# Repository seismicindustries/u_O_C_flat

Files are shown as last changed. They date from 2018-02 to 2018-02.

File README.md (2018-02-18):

# u_O_C_flat
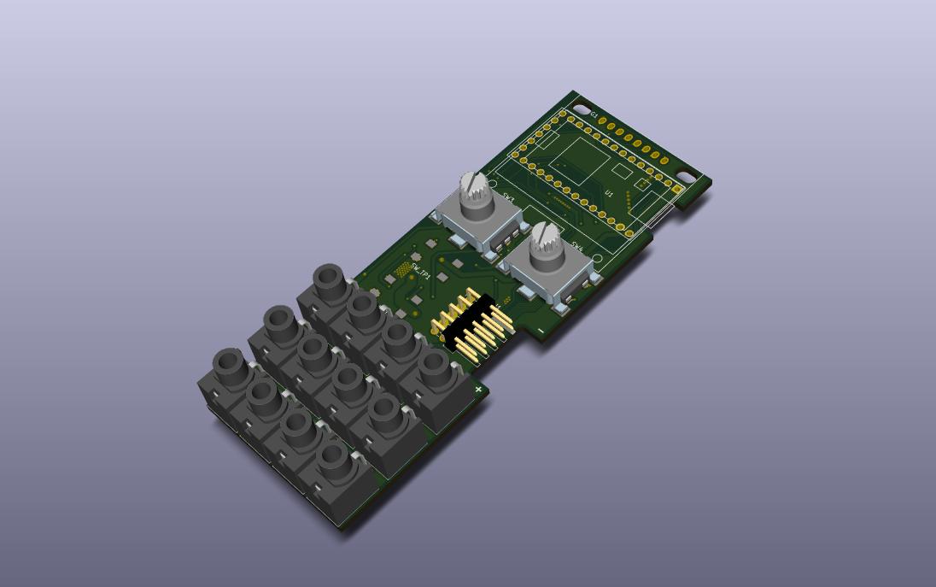
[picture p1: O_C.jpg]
render from kicad

same as the original

with the same formfactor as the u_O_C but different placement of the encoders and buttons

also the linear regulator has been replaced by a MP1469 regulator.

-> so far the design is untested. i made some PCB but i don't have my display yet...

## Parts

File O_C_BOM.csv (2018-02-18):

Refs | Value | Footprint | MFR | MPN | SPR | QTY | SPN
SW_BOT1;SW_TP1 | SW_PUSH_SMALL_H | raffilibkicad:APEM_tactile_SMD_switch_6mm | APEM | ADTSM66NV | Mouser | 2 | 642-ADTSM66NV
C1;C2;C4 | 22u | raffilibkicad:CP_Elec_7.3x4.3 | Panasonic | EEF-CX1D220R | Mouser | 3 | 667-EEF-CX1D220R
C5;C7;C8;C12;C11;C15;C26;C28;C27;C29 | 100n | raffilibkicad:C_0603 | Wurth Electronics | 8.85012E+11 | Mouser | 10 | 710-885012206095
C6 | 10u | raffilibkicad:C_0603 | TDK | C1608X5R0J106M080AB | Mouser | 1 | 810-C1608X5R0J106M
C3;C10;C14 | 1u | raffilibkicad:C_0603 | Murata | GCJ188R71E105KA01D | Mouser | 3 | 81-GCJ188R71E105KA1D
C22;C23;C24;C25 | 22p | raffilibkicad:C_0603 | Kemet | C0603C220J5GACTU | Mouser | 4 | 80-C0603C220J5G
C9;C16;C17;C18;C19;C20;C21;C13 | 470n | raffilibkicad:C_0603 | Taiyo Yuden | EMK107B7474KA-T | Mouser | 8 | 963-EMK107B7474KA-T
SW3;SW4 | Rotary_Encoder_Switch | raffilibkicad:ENCODER_PEC11_SMD | Bourns | PEC11S-9215K-H0015 | Mouser | 2 | 652-PEC11S9215KH0015
L1;L2 | 100n | raffilibkicad:Inductor_PSU_NLCV32T | TDK | NLCV32T-R10M-PFR | Mouser | 2 | 810-NLCV32T-R10M-PFR
L3 | 6u8 | raffilibkicad:Inductor_SRN4018TA_bourns | Bourns | SRN4018TA-6R8M | Mouser | 1 | 652-SRN4018TA-6R8M
G1 | Display128x64OLED | raffilibkicad:OLED_DISPLAY_128_64_1_3_inch |  |  |  | 1
J1 | CONN_02X05 | raffilibkicad:Pin_Header_Angled_2x05_Pitch2.54mm_with_space_for_con | Amphenol FCI | 649-68020-110HLF | Mouser | 1 | 68020-110HLF
R25;R26;R27;R28 | 100 | raffilibkicad:R_0603 |  |  | Mouser | 4 | 603-RC0603FR-07100RL
R1;R23;R24;R35;R36;R12;R14;R16;R18;R37;R38;R39;R40 | 100k | raffilibkicad:R_0603 | Vishay / Draloric | RCA0603100KJNEC | Mouser | 13 | 71-RCA0603100KJNEC
R43;R44;R45;R46 | 220 | raffilibkicad:R_0603 | Vishay | CRCW0603220RFKEB | Mouser | 4 | 71-CRCW0603220RFKEB
R31;R32;R33;R34 | 24k9 | raffilibkicad:R_0603 | Yageo | RC0603FR-0724K9L | Mouser | 4 | 603-RC0603FR-0724K9L
R6 | 2k | raffilibkicad:R_0603 | Yageo | RC0603FR-0724K9L | Mouser | 1 | 603-RC0603FR-072KL
R29;R30;R41;R42;R19;R20;R21;R22 | 33k | raffilibkicad:R_0603 | Panasonic | ERJ-3GEYJ333V | Mouser | 8 | 667-ERJ-3GEYJ333V
R3 | 40k2 | raffilibkicad:R_0603 |  |  | Mouser | 1 | 603-RC0805FR-0740K2L
R9;R10 | 47k | raffilibkicad:R_0603 | Yageo | RC0603FR-0747KL | Mouser | 2 | 603-RC0603FR-0747KL
R8;R7 | 510 | raffilibkicad:R_0603 | Yageo | RC0603FR-07510RL | Mouser | 2 | 603-RC0603FR-07510RL
R2;R5;R11;R13;R15;R17 | 75k | raffilibkicad:R_0603 | Bourns | CR0603-FX-2202ELF | Mouser | 6 | 652-CR0603FX-2202ELF
R4 | 7k68 | raffilibkicad:R_0603 |  |  | Mouser | 1 | 603-RC0805FR-077K68L
U4 | AP2210N-3.3TRG1_/_SOT23-3 | raffilibkicad:SOT-23 | Diodes Incorporated | AP2210N-3.3TRG1 | Mouser | 1 | 621-AP2210N-3.3TRG1
D1 | LM4040 5.0V | raffilibkicad:SOT-23 | Texas Instruments | LM4040C50IDBZR | Mouser | 1 | 595-LM4040C50IDBZR
Q1;Q2;Q3;Q4 | MMBT3904 | raffilibkicad:SOT-23 | Nexperia | MMBT3904,215 | Mouser | 4 | 771-MMBT3904T/R
U3 | MP1469 | raffilibkicad:SOT-23-6 | MPS | MP1469GJ-Z | Mouser | 1 | 946-MP1469GJZ
U5 | MCP6004 | raffilibkicad:TSSOP-14_4.4x5mm_Pitch0.65mm | Microchip | MCP6004T-I/ST | Mouser | 1 | 579-MCP6004T-I/ST
U6 | TL074 | raffilibkicad:TSSOP-14_4.4x5mm_Pitch0.65mm | Texas Instruments | TL074CPWR | Mouser | 1 | 595-TL074CPWR
U2 | DAC8565 | raffilibkicad:TSSOP-16_4.4x5mm_Pitch0.65mm | Texas Instruments | DAC8565ICPW | Mouser | 1 | 595-DAC8565ICPW
U1 | Teensy3.2 | raffilibkicad:Teensy_3_2 | SparkFun | DEV-13736 | Mouser | 1 | 474-DEV-13736
TR4;TR3;TR2;TR1;CVD1;CVC1;CVB1;CVA1;CV4;CV3;CV2;CV1 | JACK_QINGPU | raffilibkicad:jack_qingpu |  |  |  | 12

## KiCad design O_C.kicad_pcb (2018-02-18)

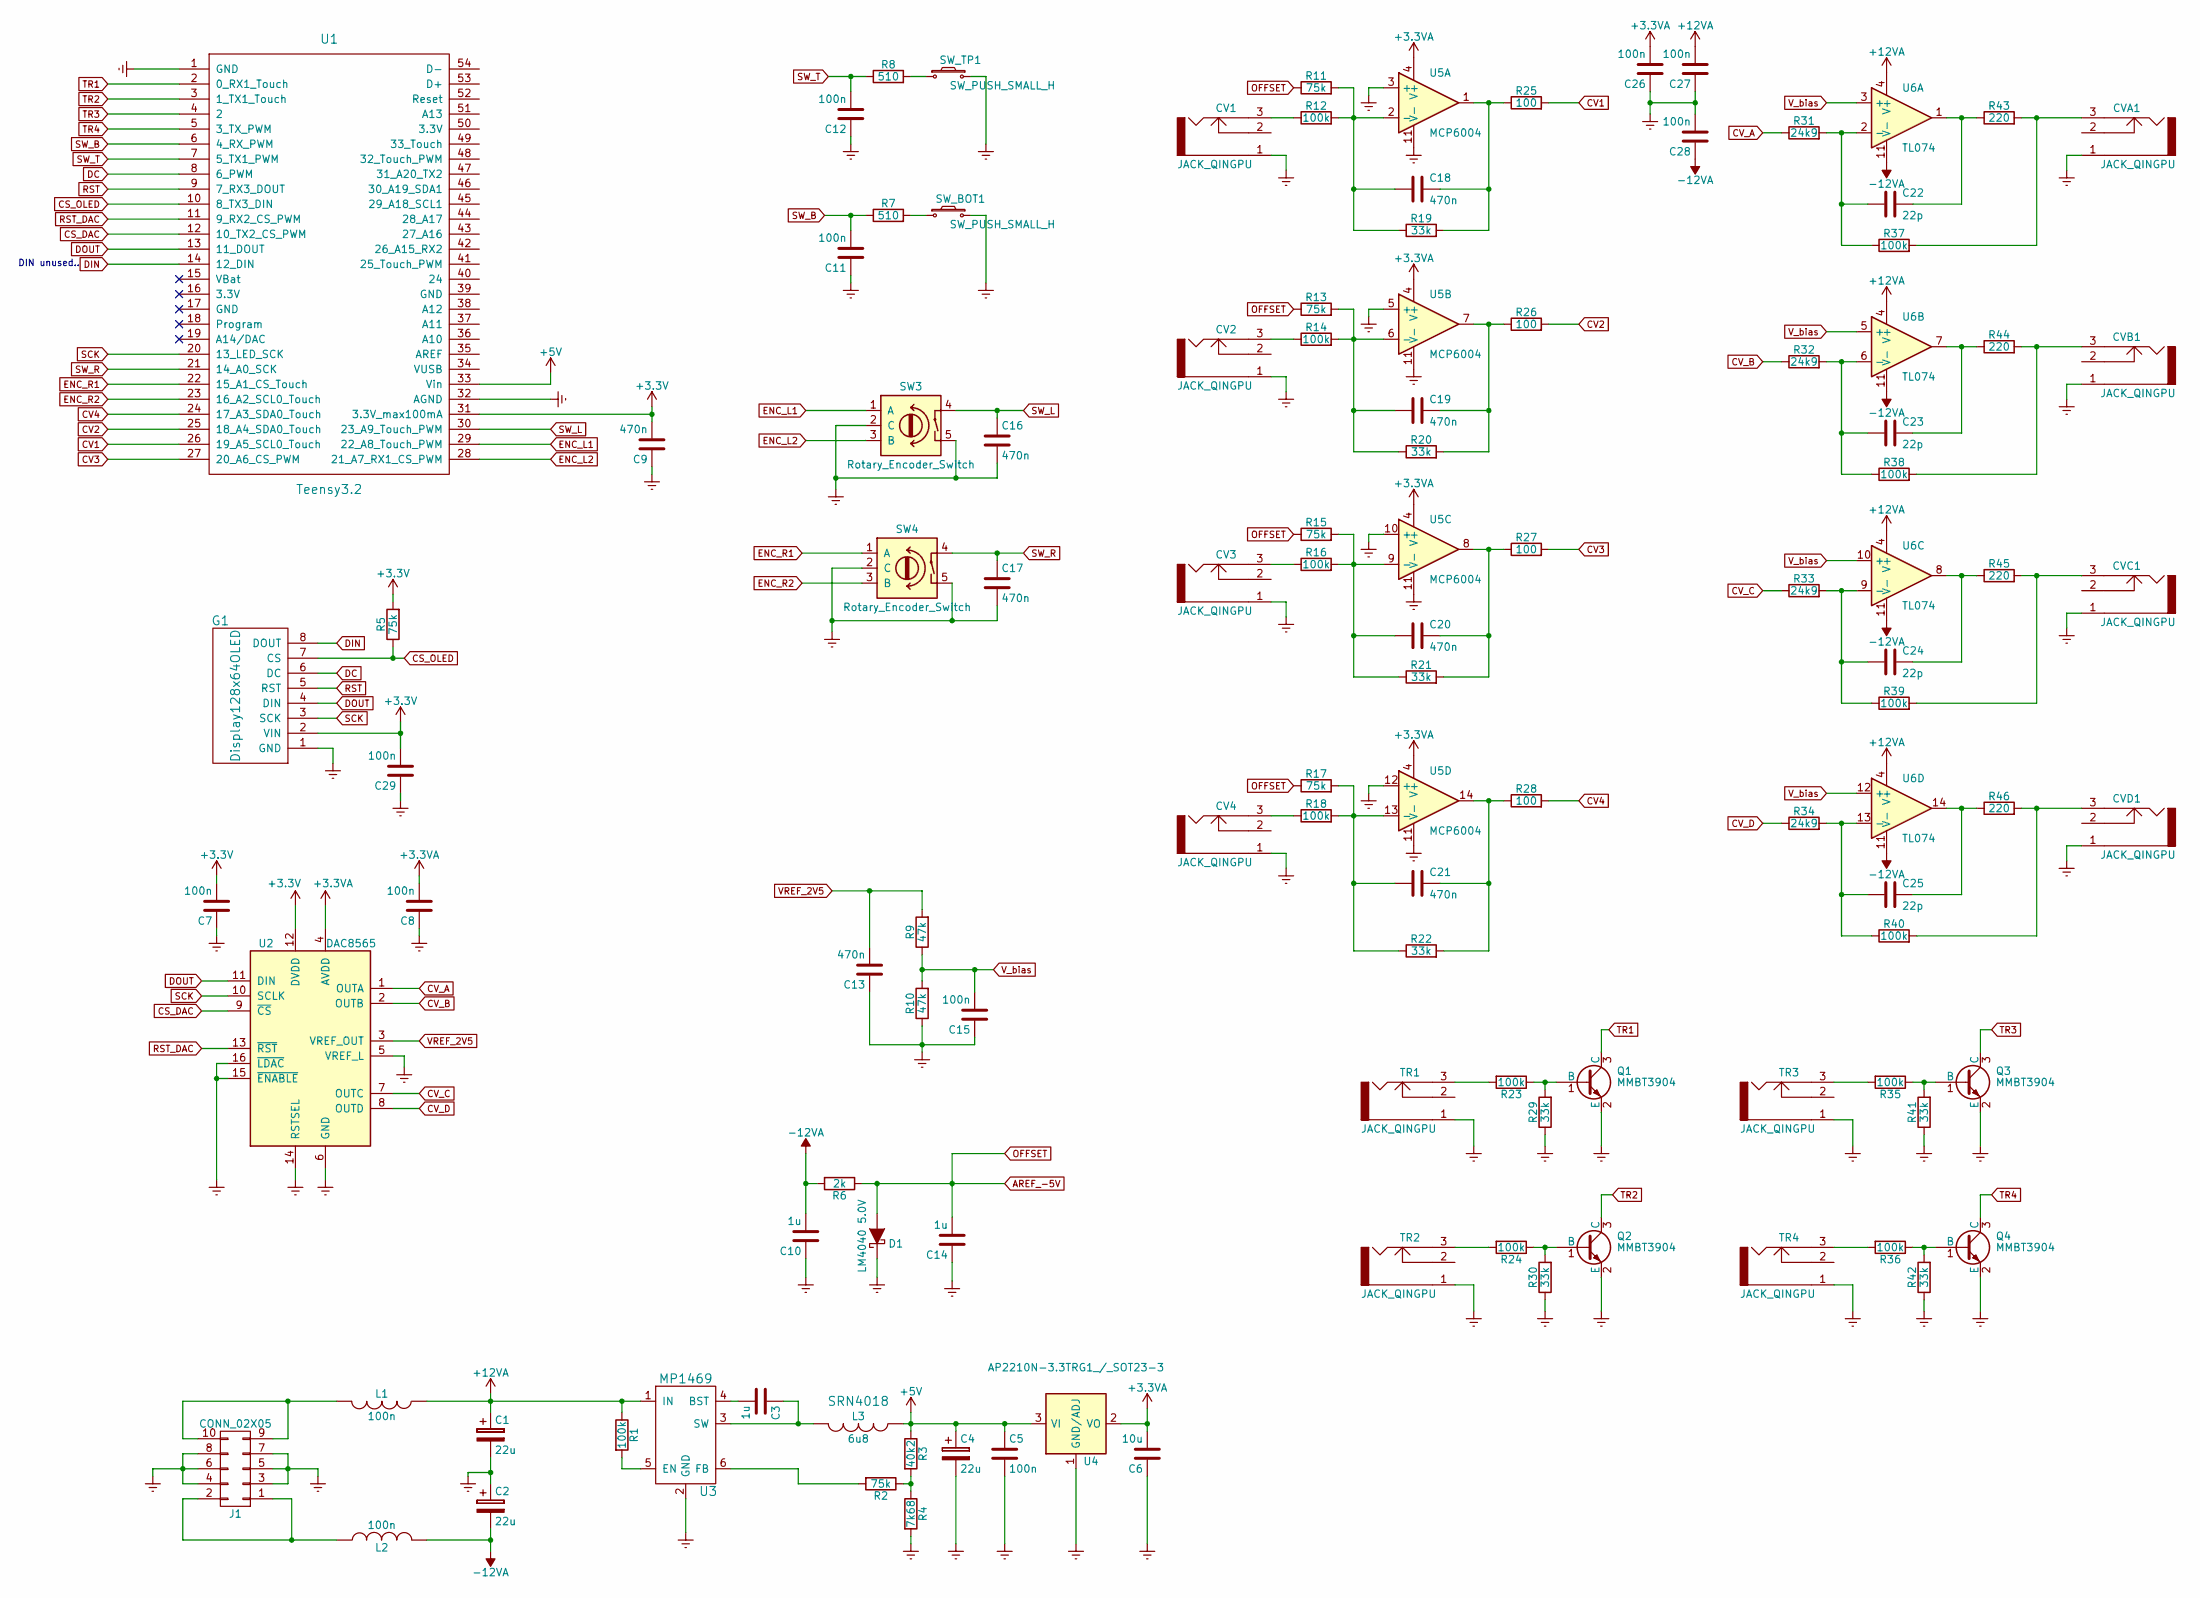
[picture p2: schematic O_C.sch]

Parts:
C1, C2, C4: 22u; CP_Elec_7.3x4.3; MPN EEF-CX1D220R
C3, C10, C14: 1u; C_0603; MPN GCJ188R71E105KA01D
C5, C7, C8, C11, C12, C15, C26, C27, C28, C29: 100n; C_0603; MPN C0603C104Z3VACTU
C6: 10u; C_0603; MPN C1608X5R0J106M080AB
C9, C13, C16, C17, C18, C19, C20, C21: 470n; C_0603; MPN EMK107B7474KA-T
C22, C23, C24, C25: 22p; C_0603; MPN C0603C220J5GACTU
CV1, CV2, CV3, CV4: JACK_QINGPU; jack_qingpu
CVA1: JACK_QINGPU; jack_qingpu
CVB1: JACK_QINGPU; jack_qingpu
CVC1: JACK_QINGPU; jack_qingpu
CVD1: JACK_QINGPU; jack_qingpu
D1: LM4040 5.0V; SOT-23; MPN LM4040C50IDBZR
G1: Display128x64OLED; OLED_DISPLAY_128_64_1_3_inch
J1: CONN_02X05; Pin_Header_Angled_2x05_Pitch2.54mm_with_space_for_con; MPN 649-68020-110HLF
L1, L2: 100n; Inductor_PSU_NLCV32T; MPN NLCV32T-R10M-PFR
L3: 6u8; Inductor_SRN4018TA_bourns; MPN SRN4018TA-6R8M
Q1, Q2, Q3, Q4: MMBT3904; SOT-23; MPN MMBT3904,215
R1, R12, R14, R16, R18, R23, R24, R35, R36, R37, R38, R39, R40: 100k; R_0603; MPN RCA0603100KJNEC
R2, R5, R11, R13, R15, R17: 75k; R_0603; MPN CR0603-FX-2202ELF
R3: 40k2; R_0603
R4: 7k68; R_0603
R6: 2k; R_0603; MPN RC0603FR-0724K9L
R7, R8: 510; R_0603; MPN RC0603FR-07510RL
R9, R10: 47k; R_0603; MPN RC0603FR-0747KL
R19, R20, R21, R22, R29, R30, R41, R42: 33k; R_0603; MPN ERJ-3GEYJ333V
R25, R26, R27, R28: 100; R_0603
R31, R32, R33, R34: 24k9; R_0603; MPN RC0603FR-0724K9L
R43, R44, R45, R46: 220; R_0603; MPN CRCW0603220RFKEB
SW3, SW4: Rotary_Encoder_Switch; ENCODER_PEC11_SMD; MPN PEC11S-9215K-H0015
SW_BOT1: SW_PUSH_SMALL_H; APEM_tactile_SMD_switch_6mm; MPN ADTSM66NV
SW_TP1: SW_PUSH_SMALL_H; APEM_tactile_SMD_switch_6mm; MPN ADTSM66NV
TR1, TR2, TR3, TR4: JACK_QINGPU; jack_qingpu
U1: Teensy3.2; Teensy_3_2; MPN DEV-13736
U2: DAC8565; TSSOP-16_4.4x5mm_Pitch0.65mm; MPN DAC8565ICPW
U3: MP1469; SOT-23-6; MPN MP1469GJ-Z
U4: AP2210N-3.3TRG1_/_SOT23-3; SOT-23; MPN AP2210N-3.3TRG1
U5: MCP6004; TSSOP-14_4.4x5mm_Pitch0.65mm; MPN MCP6004T-I/ST
U6: TL074; TSSOP-14_4.4x5mm_Pitch0.65mm; MPN TL074CPWR

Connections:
+3.3VA: C6.2, C8.2, C26.2, U2.4 (AVDD), U4.2 (VO), U5.4 (V+)
+3V3: C7.2, C9.2, C29.2, G1.2 (VIN), R5.2, U1.31 (3.3V_max100mA), U2.12 (DVDD)
+5V: C4.1, C5.1, L3.1, R3.1, U1.33 (Vin), U4.3 (VI)
+12VA: C1.1, C27.2, L1.1, R1.1, U3.1 (IN), U6.4 (V+)
-12VA: C2.2, C10.2, C28.1, L2.2, R6.2, U6.11 (V-)
AREF_-5V: C14.2, D1.2 (A), R6.1, R11.1, R13.1, R15.1, R17.1
CS_DAC: U1.12 (10_TX2_CS_PWM), U2.9 (~CS)
CS_OLED: G1.7 (CS), R5.1, U1.10 (8_TX3_DIN)
CV1: R25.2, U1.26 (19_A5_SCL0_Touch)
CV2: R26.2, U1.25 (18_A4_SDA0_Touch)
CV3: R27.2, U1.27 (20_A6_CS_PWM)
CV4: R28.2, U1.24 (17_A3_SDA0_Touch)
CV_A: R31.1, U2.1 (OUTA)
CV_B: R32.1, U2.2 (OUTB)
CV_C: R33.1, U2.7 (OUTC)
CV_D: R34.1, U2.8 (OUTD)
DC: G1.6 (DC), U1.8 (6_PWM)
DIN: G1.8 (DOUT), U1.14 (12_DIN)
DOUT: G1.4 (DIN), U1.13 (11_DOUT), U2.11 (DIN)
ENC_L1: SW3.1 (A), U1.29 (22_A8_Touch_PWM)
ENC_L2: SW3.3 (B), U1.28 (21_A7_RX1_CS_PWM)
ENC_R1: SW4.1 (A), U1.22 (15_A1_CS_Touch)
ENC_R2: SW4.3 (B), U1.23 (16_A2_SCL0_Touch)
Earth: C1.2, C2.1, C4.2, C5.2, C6.1, C7.1, C8.1, C9.1, C10.1, C11.1, C12.1, C13.1, C14.1, C15.1, C16.2, C17.2, C26.1, C27.1, C28.2, C29.1, CV1.1, CV2.1, CV3.1, CV4.1, CVA1.1, CVB1.1, CVC1.1, CVD1.1, D1.1 (K), G1.1 (GND), J1.3, J1.4, J1.5, J1.6, J1.7, J1.8, Q1.2 (E), Q2.2 (E), Q3.2 (E), Q4.2 (E), R4.2, R10.1, R29.1, R30.1, R41.1, R42.1, SW3.2 (C), SW3.5, SW4.2 (C), SW4.5, SW_BOT1.2, SW_TP1.2, TR1.1, TR2.1, TR3.1, TR4.1, U1.1 (GND), U1.32 (AGND), U2.5 (VREF_L), U2.6 (GND), U2.14 (RSTSEL), U2.15 (~ENABLE), U2.16 (~LDAC), U3.2 (GND), U4.1 (GND/ADJ), U5.3 (+), U5.5 (+), U5.10 (+), U5.11 (V-), U5.12 (+)
unnamed: C3.1, L3.2, U3.3 (SW)
unnamed: C3.2, U3.4 (BST)
unnamed: C18.1, R19.2, R25.1, U5.1
unnamed: C18.2, R11.2, R12.2, R19.1, U5.2 (-)
unnamed: C19.1, R20.2, R26.1, U5.7
unnamed: C19.2, R13.2, R14.2, R20.1, U5.6 (-)
unnamed: C20.1, R21.2, R27.1, U5.8
unnamed: C20.2, R15.2, R16.2, R21.1, U5.9 (-)
unnamed: C21.1, R22.2, R28.1, U5.14
unnamed: C21.2, R17.2, R18.2, R22.1, U5.13 (-)
unnamed: C22.1, R43.1, U6.1
unnamed: C22.2, R31.2, R37.1, U6.2 (-)
unnamed: C23.1, R44.1, U6.7
unnamed: C23.2, R32.2, R38.1, U6.6 (-)
unnamed: C24.1, R45.1, U6.8
unnamed: C24.2, R33.2, R39.1, U6.9 (-)
unnamed: C25.1, R46.1, U6.14
unnamed: C25.2, R34.2, R40.1, U6.13 (-)
unnamed: CV1.3, R12.1
unnamed: CV2.3, R14.1
unnamed: CV3.3, R16.1
unnamed: CV4.3, R18.1
unnamed: CVA1.3, R37.2, R43.2
unnamed: CVB1.3, R38.2, R44.2
unnamed: CVC1.3, R39.2, R45.2
unnamed: CVD1.3, R40.2, R46.2
unnamed: J1.1, J1.2, L2.1
unnamed: J1.9, J1.10, L1.2
unnamed: Q1.1 (B), R23.1, R29.2
unnamed: Q2.1 (B), R24.1, R30.2
unnamed: Q3.1 (B), R35.1, R41.2
unnamed: Q4.1 (B), R36.1, R42.2
unnamed: R1.2, U3.5 (EN)
unnamed: R2.1, R3.2, R4.1
unnamed: R2.2, U3.6 (FB)
unnamed: R7.2, SW_BOT1.1
unnamed: R8.2, SW_TP1.1
unnamed: R23.2, TR1.3
unnamed: R24.2, TR2.3
unnamed: R35.2, TR3.3
unnamed: R36.2, TR4.3
RST: G1.5 (RST), U1.9 (7_RX3_DOUT)
RST_DAC: U1.11 (9_RX2_CS_PWM), U2.13 (~RST)
SCK: G1.3 (SCK), U1.20 (13_LED_SCK), U2.10 (SCLK)
SW_B: C11.2, R7.1, U1.6 (4_RX_PWM)
SW_L: C16.1, SW3.4, U1.30 (23_A9_Touch_PWM)
SW_R: C17.1, SW4.4, U1.21 (14_A0_SCK)
SW_T: C12.2, R8.1, U1.7 (5_TX1_PWM)
TR1: Q1.3 (C), U1.2 (0_RX1_Touch)
TR2: Q2.3 (C), U1.3 (1_TX1_Touch)
TR3: Q3.3 (C), U1.4 (2)
TR4: Q4.3 (C), U1.5 (3_TX_PWM)
VREF_2V5: C13.2, R9.2, U2.3 (VREF_OUT)
V_bias: C15.2, R9.1, R10.2, U6.3 (+), U6.5 (+), U6.10 (+), U6.12 (+)

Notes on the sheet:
DIN unused..

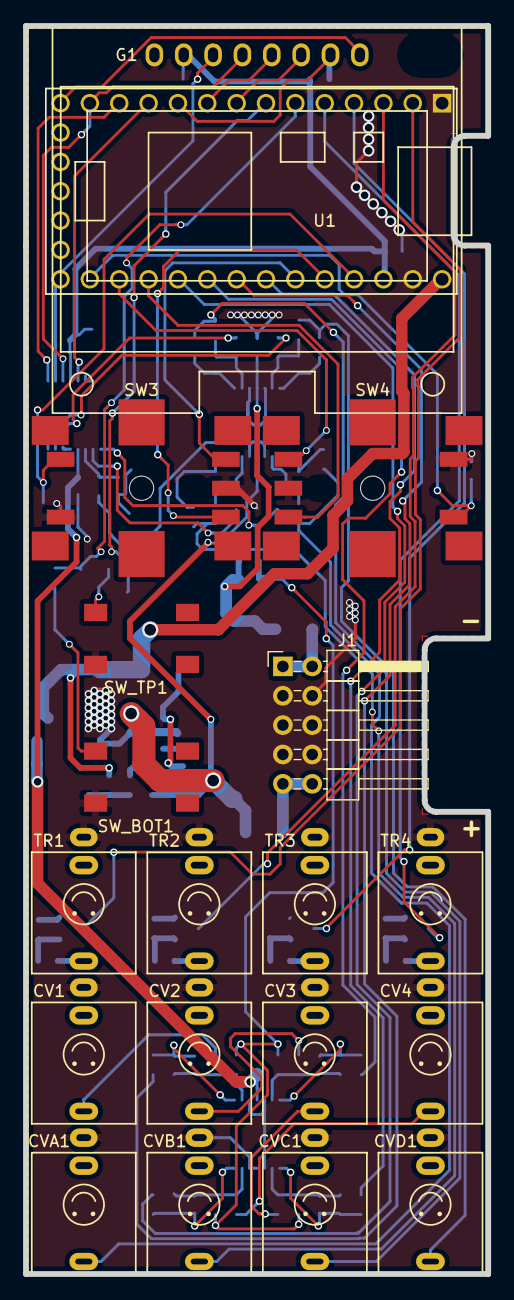
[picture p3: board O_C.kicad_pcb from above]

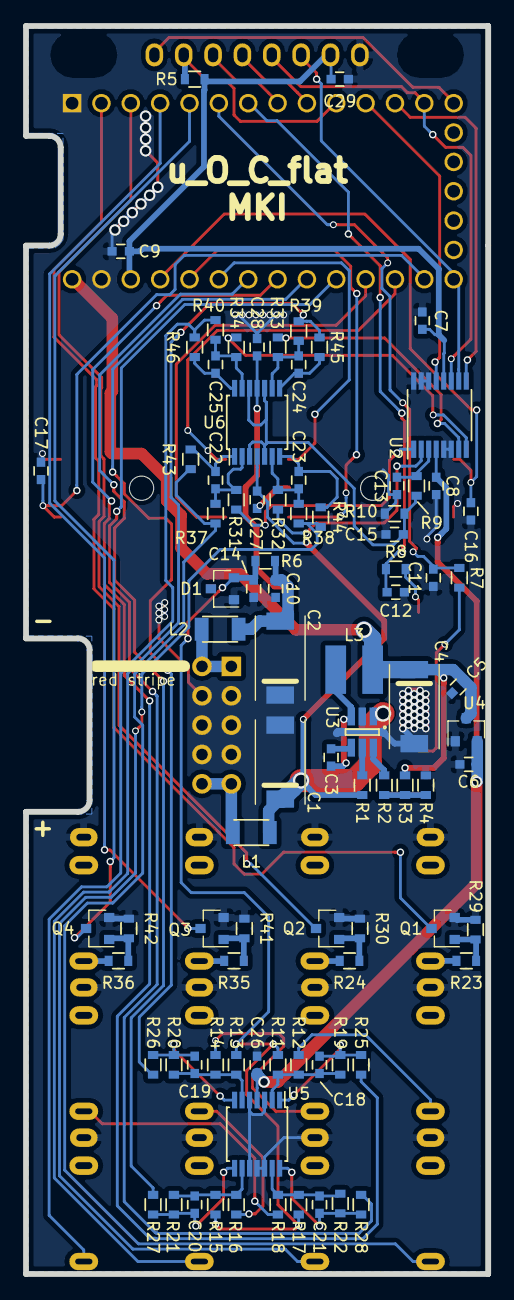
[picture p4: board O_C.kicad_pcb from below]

Board: 2 copper layers, 40.0 x 108.0 mm, 107 parts (88 on the bottom side), 78 nets.
